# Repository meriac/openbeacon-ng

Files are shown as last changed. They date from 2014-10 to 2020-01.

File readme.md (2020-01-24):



### Introduction

The [OpenBeacon.org](https://www.openbeacon.org/) project provides Active 2.4 GHz RFID Realtime Proximity and Position Tracking using the BlueTooth Low Energy (BLE) compatible [nRF51822](https://www.nordicsemi.com/eng/Products/Bluetooth-Smart-Bluetooth-low-energy/nRF51822) chip from Nordic Semiconductors.

Location tracking using [OpenBeacon tags](https://www.openbeacon.org/device.html) can be implemented by running an [OpenBeacon proximity tag firmware](https://github.com/meriac/openbeacon-ng/tree/master/firmware/nRF51/tag-proximity) that regularly transmits beacon packets. Such packets can then be received by OpenBeacon base stations in the vicinity. Signals received by one or more base stations can then be used to determine the position of each tag in real time.

The proximity feature additionally allows to resolve human contacts by sending detecting other tags in a range of up to 6 meters and a resolution of approximately 0.5 meters. Once a contact is detected, that information is forwarded by the surrounding PoE Ethernet readers to the server infrastructure. Due to the shielding effect of the body, face-to-face contacts can be accurately detected. Optional encryption can make sure, that only base stations inside the system can read the packet information.

On this page you can find the OpenBeacon proximity tag [hardware design](https://github.com/meriac/openbeacon-ng/tree/master/hardware) and the [firmware source code](https://github.com/meriac/openbeacon-ng). You can find more information here:

- See documentation on [Turning the BBC micro:bit into an OpenBeacon Reader](docs/microbit.md) for live sniffing of OpenBeacon sightings.

- [QuickStart for OpenBeacon Tracking](docs/quickstart.md) - this covers serial logging only. For networked live logging, please [contact us](mailto:info@bitmanufactory.com) for more information on our Linux-based network readers (Wifi & Ethernet).

- [Updating your tag firmware](docs/firmware-update.md) - download our latest compiled firmware and update your tags to the latest features.

- [OpenBeacon.org](https://www.openbeacon.org/device.html) Active 2.4GHz RFID Proximity TAG based on the nRF51822 chip from Nordic Semiconductors.

- [SocioPatterns.org](http://www.sociopatterns.org) research project on High-Resolution Social Networks from Wearable Proximity Sensors

- [Contact us](mailto:info@bitmanufactory.com) for further information.

### Acknowledgements

Although the code contributions are acknowledged in the source code headers and history [log files](https://github.com/meriac/openbeacon-ng/commits/master) of the [github repository](https://github.com/meriac/openbeacon-ng), this project lives from invaluable user contributions like rigorous testing, constant suggestion of new features and regular real-life deployments in the field.

The OpenBeacon Team wants to thank [Ciro Cattuto](http://www.cirocattuto.info/) from the [ISI Foundation](http://www.isi.it/) for the great collaboration during the joint development, the ongoing moral support and innovative deployments of our systems.

We especially want to thank Ciro and the [SocioPatterns collaboration](http://www.sociopatterns.org) for providing the scientific background for our platform, the media exposure and the deployments needed for the survival of our project.

### License Information

Please [contact us](mailto:license@bitmanufactory.com) for [obtaining a dual-licensed **closed source license**](mailto:license@bitmanufactory.com?subject=Alternative%20License).

#### Hardware

If you wish, you are free to manufacture the tags yourself. For that purpose you can find the schematics and hardware designs in the directory **hardware**.  The hardware design files in that folder are licensed under the Attribution-ShareAlike 4.0 International ([CC BY-SA 4.0](http://creativecommons.org/licenses/by-sa/4.0/)). We specifically allow commercial usage - as long as you mention the origin of our original design openly.

You can choose to use our services for bulk orders and for custom hardware development based on this and other designs we created in the past. Your financial support allows us to continue working on this awesome project - any help is highly appreciated!

#### Software

The files in the folders **firmware** and **host** are free software. You can redistribute it and/or modify them under the terms of the GNU General Public License as published by the Free Software Foundation (version 2). This program is distributed in the hope that it will be useful, but **without any warranty**; without even the implied warranty of merchantibility or fitness for a particular purpose. See the [GNU General Public License v2](http://www.gnu.org/licenses/gpl-2.0.html) for more details.

### Background Information

#### OpenBeacon.org

The [OpenBeacon.org](https://www.openbeacon.org) project was founded by [Milosch Meriac](https://www.meriac.com) and [Brita Meriac](mailto:brita@bitmanufaktory.com) in 2006 at the Berlin located company Bitmanufaktur GmbH as an open platform for active RFID applications operating in the license free 2.4GHz ISM band. OpenBeacon is based on Open Source software and a very flexible and a open design of a reprogrammable low cost Open Source Active 2.4GHz RFID hardware module. The RFID tag and reader firmware sources are available under GPL license the and tag hardware schematics are available under the open [Creative Commons license](https://creativecommons.org/). We encourage the development of new ideas for OpenBeacon setups and firmware improvements.

#### SocioPatterns

[SocioPatterns](http://www.sociopatterns.org) is an international research collaboration that uses wearable proximity sensors to map human spatial behavior in a variety of environments such as schools, hospitals, offices and social gatherings. During the last 6 years, the SocioPatterns researchers have designed and supervised over 25 data collection campaigns in 10 countries, involving over 50,000 subjects. The resulting high-resolution social networks, [shared with the public](http://www.sociopatterns.org/datasets/) whenever possible, have been used to investigate human mobility, time-varying social networks, infectious disease dynamics, location-based services, and more. The results are reported in 30+ [peer-reviewed scientific publications](http://www.sociopatterns.org/publications/) and have been featured by the [international press](http://www.sociopatterns.org/press/).

The SocioPatterns collaboration was founded by researchers and developers from the following institutions and companies:

- [ISI Foundation](http://www.isi.it/) -- Turin, Italy

- [CNRS - Centre de Physique Theorique](http://www.cpt.univ-mrs.fr) -- Marseille, France

- [ENS Lyon - Laboratoire de Physique](http://www.ens-lyon.fr/PHYSIQUE/) -- Lyon, France

- [Bitmanufactory](https://www.bitmanufactory.com/about/) -- Cambridge, United Kingdom

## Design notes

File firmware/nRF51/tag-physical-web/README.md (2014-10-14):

## OpenBeacon Physical Web Beacon

Our code is hosted on [github.com](https://github.com/meriac/openbeacon-ng). Software development is officially supported for OS X and Linux. Please use the latest [gcc-arm-none-eabi](https://launchpad.net/gcc-arm-embedded) toolchain from launchpad. Thanks a lot to ARM for maintaining [GNU Tools for ARM Embedded Processor](https://launchpad.net/gcc-arm-embedded).

### Hello World!
To demonstrate usage of the included 3D acceleration sensor the included hello world example transmits the URL only while facing forward.

Get the [hardware design](http://get.openbeacon.org/device.html) and [development environment](http://get.openbeacon.org/source/) for creating your own beacons.

You can find the main loop in [firmware/nRF51/tag-physical-web/entry.c](https://github.com/meriac/openbeacon-ng/blob/master/firmware/nRF51/tag-physical-web/entry.c).

### Quick start
For compiling and flashing the firmware source you need to get the [source code](https://github.com/meriac/openbeacon-ng):
```bash
# get the latest source code
git clone https://github.com/meriac/openbeacon-ng
# change into tag directory
cd openbeacon-ng/firmware/nRF51/tag-physical-web
# compile and flash code
make clean flash
```
As you can see the makefile directly supports flashing from command line (under OSX and Linux) by using a [Segger J-Link debug probe](https://www.segger.com/jlink-software.html) from the [Nordic nRF51822 development kit](http://uk.mouser.com/Search/Refine.aspx?Keyword=949-NRF51822-DK).

### Support ###

Please sign up to our [OpenBeacon Group](https://groups.google.com/forum/#!forum/openbeacon) or contact us at [developer@openbeacon.org](mailto:developer@openbeacon.org?subject=Developer%20Support).

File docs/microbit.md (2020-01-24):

# Turning the BBC micro:bit into an OpenBeacon Reader

## Overview

The [BBC micro:bit](https://microbit.org/guide/features/) is a handheld, programmable micro-computer that can be used for all sorts of cool creations, from robots to musical instruments – the possibilities are endless. You can [buy it at most electronis stores](https://microbit.org/resellers/) and at [Amazon](https://www.amazon.com/s?k=micro%3Abit&ref=bl_dp_s_web_0).

In this tutorial we'll show you how to use the micro:bit as an OpenBeacon reader. You can find the [reader-prox-microbit](../firmware/nRF51/reader-prox-microbit) firmware sources in our github repository. We published a precompiled binary firmware image of reader-prox-microbit to turn your micro:bit into an OpenBeacon USB reader. 

## Install Firmware

We provide the [latest precompiled firmware release](../../../releases) in our GitHub repository. Please download the zip file, unpack on your local computer and choose the reader-prox-microbit.bin firmware. Please connect the micro:bit to your computer using a micro USB cable.

Drag & drop the reader-prox-microbit firmware file onto your external device “MICROBIT” within your file manager or finder. The board automatically starts updating the firmware of the main CPU. The process takes less than a second. The red LED square on the board light up five time to indicate a successful boot and resumes fast blinking afterwards in case of picking up traffic by OpenBeacon tags in proximity.

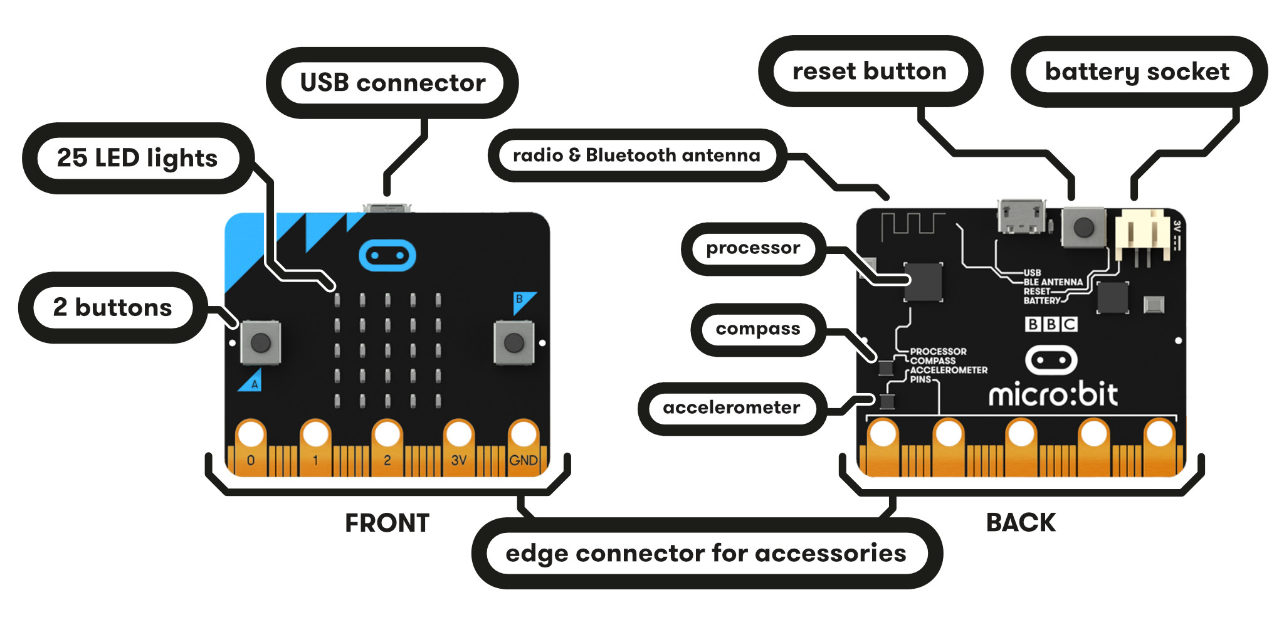
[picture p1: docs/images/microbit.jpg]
Image of micro:bit PCB


## Using the micro:bit OpenBeacon USB Reader

For each blink the received data is sent of over USB serial to the host PC. To see the data you need to connect to the USB serial port created by the micro:bit PCB at 115200 Baud transmission speed (Baudrate). The micro:bit starts in compatibility mode and show the received data in binary mode only:

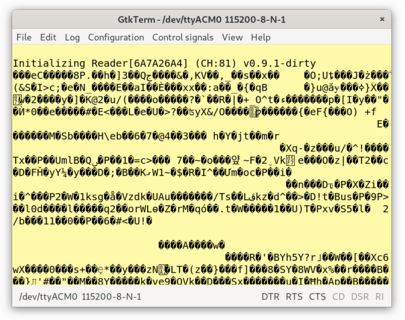
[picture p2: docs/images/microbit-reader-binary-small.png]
Image of micro:bit PCB


By pressing "Button B" briefly, the device can be switched to human readable text mode:

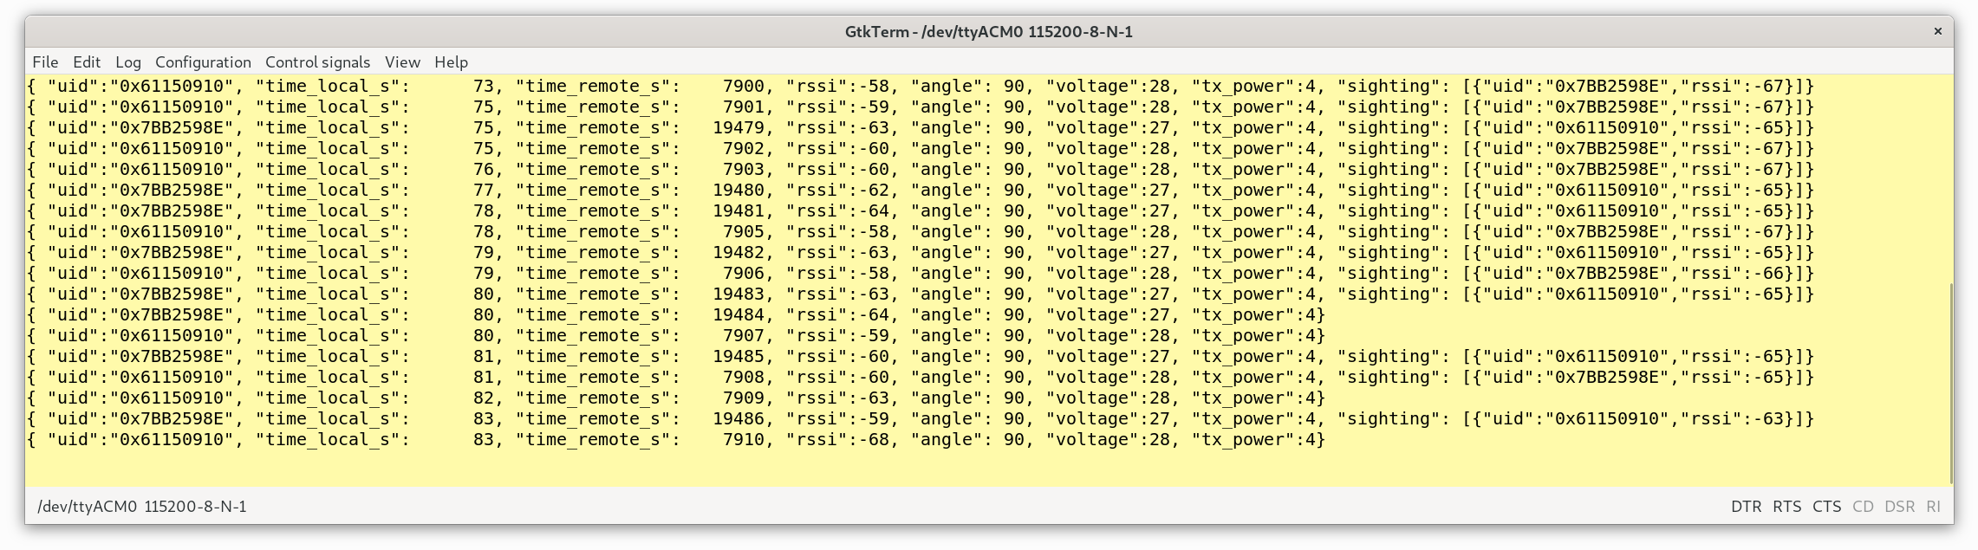
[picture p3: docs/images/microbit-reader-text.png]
Image of micro:bit PCB


By pressing "Button A" briefly, the device can be switched back to binary mode.

For every tag in range of the reader, one line of the data below is printed. You can see below, that the 
tag with ID 0x4A1A13B5 is in very close proximity to three other tags with the IDs 0x7EA7D3ED, 0x3DCFB9B4
and 0x1AFF5471. The reader picks up the reporting tag at -82dBm. Additionally  for each of the tags in
sight of the reporting tag, RSSI-values are reported as well (-63dBm, -66dBm, 58dBm).

The tag also reports its angle, battery voltage and its internal time stamp **time_remote_s**
(seconds after battery insertion). The key here is the **time_local_s** field - which represents the time
in seconds receiving this sighting ince starting the micro:bit.

#### Example Output
```JSON
{
	"uid": "0x4A1A13B5",
	"time_local_s": 1535269163,
	"time_remote_s": 567,
	"rssi": -82,
	"angle": 90,
	"voltage": 28,
	"tx_power": 4,
	"sighting": [{
		"uid": "0x7EA7D3ED",
		"rssi": -63
	}, {
		"uid": "0x3DCFB9B4",
		"rssi": -66
	}, {
		"uid": "0x1AFF5471",
		"rssi": -58
	}]
}
```

## Using openbeacon-sniffer host software with the micro:bit

Below you can find a quick example on how to extract live tag data on an Apple MacBook. In case you see errors trying running the commands ```git``` or ```make``` below, you might have to install them first by running ```xcode-select --install```.

> Please note that the software expects the tag to be in its default mode - the binary mode. The packet decryption and decoding is happening in the host software.

For every tag in range of the reader, one line of the data below is printed. You can see below, that the 
tag with ID 0x4A1A13B5 is in very close proximity to three other tags with the IDs 0x7EA7D3ED, 0x3DCFB9B4
and 0x1AFF5471. The reader picks up the reporting tag at -82dBm. Additionally  for each of the tags in
sight of the reporting tag, RSSI-values are reported as well (-63dBm, -66dBm, 58dBm).

The tag also reports its angle, battery voltage and its internal time stamp **time_remote_s**
(seconds after battery insertion). The key here is the **time_local_s** field - which represents the time
receiving this sighting at the host in seconds.
The time unit for the local time is [Unix Epoch Time](https://www.epochconverter.com/) - which is the number of seconds that have elapsed since January 1, 1970 (midnight UTC/GMT).
By combining the local time and the remote tags time, the log files for each tag can be converted into the common local time.

#### Example Usage
```bash
# Download Sources
git clone https://github.com/meriac/openbeacon-ng
# Change into the openbeacon-sniffer host software directory
cd openbeacon-ng/host/openbeacon-sniffer/

# Compile software
make
# gcc -O3 -W -Wall -Werror -I.  -D_THREAD_SAFE -D_REENTRANT  -c -o openbeacon_sniffer.o openbeacon_sniffer.c
# gcc -O3 -W -Wall -Werror -I.  -D_THREAD_SAFE -D_REENTRANT  -c -o crypto.o crypto.c
# gcc -O3 -W -Wall -Werror -I.  -D_THREAD_SAFE -D_REENTRANT openbeacon_sniffer.o crypto.o -o openbeacon_sniffer

# Run software - note that the '*' is automatically expanded to the device name of your
# OpenBeacon programmer. Each had a different name - mine is for example /dev/tty.usbserial-AK0535TL
# The last (and optional) parameter is the optional baud rate setting - in our case 115200 Baud.
./openbeacon_sniffer /dev/tty.usbserial-* 115200
#  opening /dev/ttyACM0 @ 115200 Baud
#  { "uid":"0x4A1A13B5", "time_local_s":1535276483, "time_remote_s":     382, "rssi":-84, "angle": 90, "voltage":2.7, "tx_power":4}
#  { "uid":"0x1AFF5471", "time_local_s":1535276484, "time_remote_s":    7894, "rssi":-71, "angle": 90, "voltage":2.8, "tx_power":4}
#  { "uid":"0x7EA7D3ED", "time_local_s":1535276484, "time_remote_s":    7897, "rssi":-78, "angle": 90, "voltage":2.8, "tx_power":4, "sighting": [{"uid":"0x4A1A13B5","rssi":-66},{"uid":"0x1AFF5471","rssi":-57}]}
#  { "uid":"0x4A1A13B5", "time_local_s":1535276484, "time_remote_s":     383, "rssi":-83, "angle": 90, "voltage":2.8, "tx_power":4}
#  { "uid":"0x7EA7D3ED", "time_local_s":1535276484, "time_remote_s":    7898, "rssi":-82, "angle": 90, "voltage":2.8, "tx_power":4}
#  { "uid":"0x1AFF5471", "time_local_s":1535276485, "time_remote_s":    7895, "rssi":-74, "angle": 90, "voltage":2.8, "tx_power":4, "sighting": [{"uid":"0x4A1
```
For writing the collected tag data into a file, you simply redirect into a log file:
```bash
./openbeacon_sniffer /dev/tty.usbserial-* 115200 >>logfile.json
```
Please note that '>>' keeps on appending to **logfile.json** when you run openbeacon_sniffer multiple
times. This way you can combine data from multiple runs in case you have to replaunch openbeacon_sniffer.

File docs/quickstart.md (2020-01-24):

# QuickStart for OpenBeacon Tracking

## Turning the BBC micro:bit into an OpenBeacon Reader

See documentation on [Turning the BBC micro:bit into an OpenBeacon Reader](microbit.md) for live sniffing of OpenBeacon sightings. For using the [OpenBeacon Programmer](https://www.openbeacon.org/device.html) instead for offline data data dumping and for live OpenBeacon monotoring, see the documentation below.

## Offline Logging

When using the [Proximity Tag](../firmware/nRF51/tag-proximity) firmware,
tags can store many days of tag sightings in their proximity inside their 8MB external flash storage by using data compression.

For retrieving the stored data, we made the [tag-dumper](../host/tag-dumper) host software available. An [OpenBeacon Programmer](https://www.openbeacon.org/device.html) is used to connecting tag to a host computer for data extraction. **Always remove batteries from tags before placing them into OpenBeacon Programmer. You might destroy the reader or the tag otherwise.**

For each observation of different tags, the proximity tag stores the local time when observing the
opposite tag, the power level of the received data packet in dBm, the current angle of the tag and the
remote tag id **tag_them**. For convenience in the data processing, [tag-dumper](../host/tag-dumper) also
displays the tag ID of the currently connected tag.

> In case the tag is power-cycled, the tag time starts counting from zero again. To protect
> previous data, it is not erased unless explicitely wanted. To show the user that the tag is now counting
> at a different time offset, the rumber in **group** is incremented.
>
> For simplicity we therefore encourage to erase the tag before deployment using the programmer -
> and not to insert batteries before tags are handed out to users. These tags should therefore only
> ever display a group number of '1' and multiple time offsets can be therefore ignored.

### Retreving Offline Data

Below you can find a quick example on how to extract tag data on an Apple MacBook.
First you need to connect the [OpenBeacon Programmer](https://www.openbeacon.org/device.html) to your
laptop by using a MicroUSB cable. The nRF51-DK development kit does not need to be connected for extracting data - the development kit is only required for updating tag firmware.

> Please [update the  firmware](firmware-update.md) of your tag to **tag-proximity-log-tag.bin**
> for using the offline logging mode.

In case you see errors trying running the commands ```git``` or ```make``` below,
you might have to install them first by running ```xcode-select --install```.
```bash
# Download Sources
git clone https://github.com/meriac/openbeacon-ng
# Change into the tag-dumper host software directory
cd openbeacon-ng/host/tag-dumper/
# Compile software
make
# Run software - note that the '*' is automatically expanded to the device name of your
# OpenBeacon programmer. Each had a different name - mine is for example /dev/tty.usbserial-AK0535TL
./tag-dumper /dev/tty.usbserial-*
#  Received Tag ID=0x4A1A13B5
#  Received Tag ID=0x4A1A13B5
#  Received Tag ID=0x4A1A13B5
#  Received Tag ID=0x4A1A13B5
```
After running tag-dumper, it will print once per second *Received Tag ID=0x.....*.

If you now press the button on the tag for one second, it will start dumping stored data. Here's an
single example dataset similar to the ones you will see:
```JSON
{
	"tag_me": "0x4A1A13B5",
	"tag_them": "0x1AFF5471",
	"time_local_s": 3027,
	"time_remote_s": 3033,
	"rssi": -58,
	"angle": 90,
	"group": 1
}
```
For writing the collected tag data into a file, you simply redirect into a log file:
```bash
./tag-dumper /dev/tty.usbserial-* >>logfile.json
#  Received Tag ID=0x4A1A13B5
#  Found new log group[0] at page 0
#  Received Tag ID=0x4A1A13B5
```
Please note that '>>' keeps on appending to **logfile.json** when you run tag-dumper multiple times.
This way you can combine data from multiple runs in case you have to replaunch the tag-dumper.

### Erasing the tag

After dumping the data, you might want to erase the tag again to prime it for collecting new data.
For erasing the tag, you need to press the button on the tag for more than 3 seconds till the LED
starts blinking very quickly. Erasing the tag takes 10's of seconds. Once the erasing stopped,
the tag will go back into idle mode.

## Live Wireless Sniffing of OpenBeacon Tags

> See latest documentation on [Turning the BBC micro:bit into an OpenBeacon Reader](microbit.md) for live sniffing of OpenBeacon sightings.

The same hardware as used can be used to observe tags in operation. By using the [reader-prox](../firmware/nRF51/reader-prox) firmware and the [openbeacon-sniffer](../host/openbeacon-sniffer) software, a tag sitting
in the [OpenBeacon Programmer](https://www.openbeacon.org/device.html) sniffs and decodes tag
transmissions off the air.

For every tag in range of the reader, one line of the data below is printed. You can see below, that the 
tag with ID 0x4A1A13B5 is in very close proximity to three other tags with the IDs 0x7EA7D3ED, 0x3DCFB9B4
and 0x1AFF5471. The reader picks up the reporting tag at -82dBm. Additionally  for each of the tags in
sight of the reporting tag, RSSI-values are reported as well (-63dBm, -66dBm, 58dBm).

The tag also reports its angle, battery voltage and its internal time stamp **time_remote_s**
(seconds after battery insertion). The key here is the **time_local_s** field - which represents the time
receiving this sighting at the host running [openbeacon-sniffer](../host/openbeacon-sniffer).
The time unit for the local time is [Unix Epoch Time](https://www.epochconverter.com/) - which is the number of seconds that have elapsed since January 1, 1970 (midnight UTC/GMT).
By combining the local time and the remote tags time, the log files for each tag can be converted into the common local time.

```JSON
{
	"uid": "0x4A1A13B5",
	"time_local_s": 1535269163,
	"time_remote_s": 567,
	"rssi": -82,
	"angle": 90,
	"voltage": 2.8,
	"tx_power": 4,
	"sighting": [{
		"uid": "0x7EA7D3ED",
		"rssi": -63
	}, {
		"uid": "0x3DCFB9B4",
		"rssi": -66
	}, {
		"uid": "0x1AFF5471",
		"rssi": -58
	}]
}
```

### Retreving Live Data
Below you can find a quick example on how to extract tag data on an Apple MacBook.
First you need to connect the [OpenBeacon Programmer](https://www.openbeacon.org/device.html) to your
laptop by using a MicroUSB cable. The nRF51-DK development kit does not need to be connected for extracting data - the development kit is only required for updating tag firmware.

> Please [update the firmware](firmware-update.md) of your tag to **reader-prox.bin**
> for running live wireless sniffing.

In case you see errors trying running the commands ```git``` or ```make``` below,
you might have to install them first by running ```xcode-select --install```.
```bash
# Download Sources
git clone https://github.com/meriac/openbeacon-ng
# Change into the openbeacon-sniffer host software directory
cd openbeacon-ng/host/openbeacon-sniffer/

# Compile software
make
#  gcc -O3 -W -Wall -Werror -I. -D_THREAD_SAFE -D_REENTRANT  -c -o openbeacon_sniffer.o openbeacon_sniffer.c
#  gcc -O3 -W -Wall -Werror -I. -D_THREAD_SAFE -D_REENTRANT  -c -o crypto.o crypto.c
#  gcc -O3 -W -Wall -Werror -I. -D_THREAD_SAFE -D_REENTRANT  -c -o crc32.o crc32.c
#  gcc -O3 -W -Wall -Werror -I. -D_THREAD_SAFE -D_REENTRANT openbeacon_sniffer.o crypto.o crc32.o -o openbeacon_sniffer

# Run software - note that the '*' is automatically expanded to the device name of your
# OpenBeacon programmer. Each had a different name - mine is for example /dev/tty.usbserial-AK0535TL
./openbeacon_sniffer /dev/tty.usbserial-*
#  fd=3
#  { "uid":"0x4A1A13B5", "time_local_s":1535276483, "time_remote_s":     382, "rssi":-84, "angle": 90, "voltage":2.7, "tx_power":4}
#  { "uid":"0x1AFF5471", "time_local_s":1535276484, "time_remote_s":    7894, "rssi":-71, "angle": 90, "voltage":2.8, "tx_power":4}
#  { "uid":"0x7EA7D3ED", "time_local_s":1535276484, "time_remote_s":    7897, "rssi":-78, "angle": 90, "voltage":2.8, "tx_power":4, "sighting": [{"uid":"0x4A1A13B5","rssi":-66},{"uid":"0x1AFF5471","rssi":-57}]}
#  { "uid":"0x4A1A13B5", "time_local_s":1535276484, "time_remote_s":     383, "rssi":-83, "angle": 90, "voltage":2.8, "tx_power":4}
#  { "uid":"0x7EA7D3ED", "time_local_s":1535276484, "time_remote_s":    7898, "rssi":-82, "angle": 90, "voltage":2.8, "tx_power":4}
#  { "uid":"0x1AFF5471", "time_local_s":1535276485, "time_remote_s":    7895, "rssi":-74, "angle": 90, "voltage":2.8, "tx_power":4, "sighting": [{"uid":"0x4A1
```
For writing the collected tag data into a file, you simply redirect into a log file:
```bash
./openbeacon_sniffer /dev/tty.usbserial-* >>logfile.json
```
Please note that '>>' keeps on appending to **logfile.json** when you run openbeacon_sniffer multiple
times. This way you can combine data from multiple runs in case you have to replaunch openbeacon_sniffer.

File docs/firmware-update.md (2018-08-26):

# Updating the OpenBeacon Tag

## Connecting Nordic nRF51-DK development kit and OpenBeacon Programmer

The [OpenBeacon Programmer](https://www.openbeacon.org/device.html) connects with a flat ribbon cable to the nRF51-development board. Please make sure, that the red marking on the flat cable is pointing towards the USB connector of the OpenBeacon Programmer. Use the pins labeled “Debug Out” next to the USB connector to connect the flat ribbon cable to the the nRF51-development board. Both boards, OpenBeacon Programmer and nRF51, use a Micro-USB cable each with your local laptop or computer. Slide the switch next to the USB connector on the nRF51-development board to position “ON”.

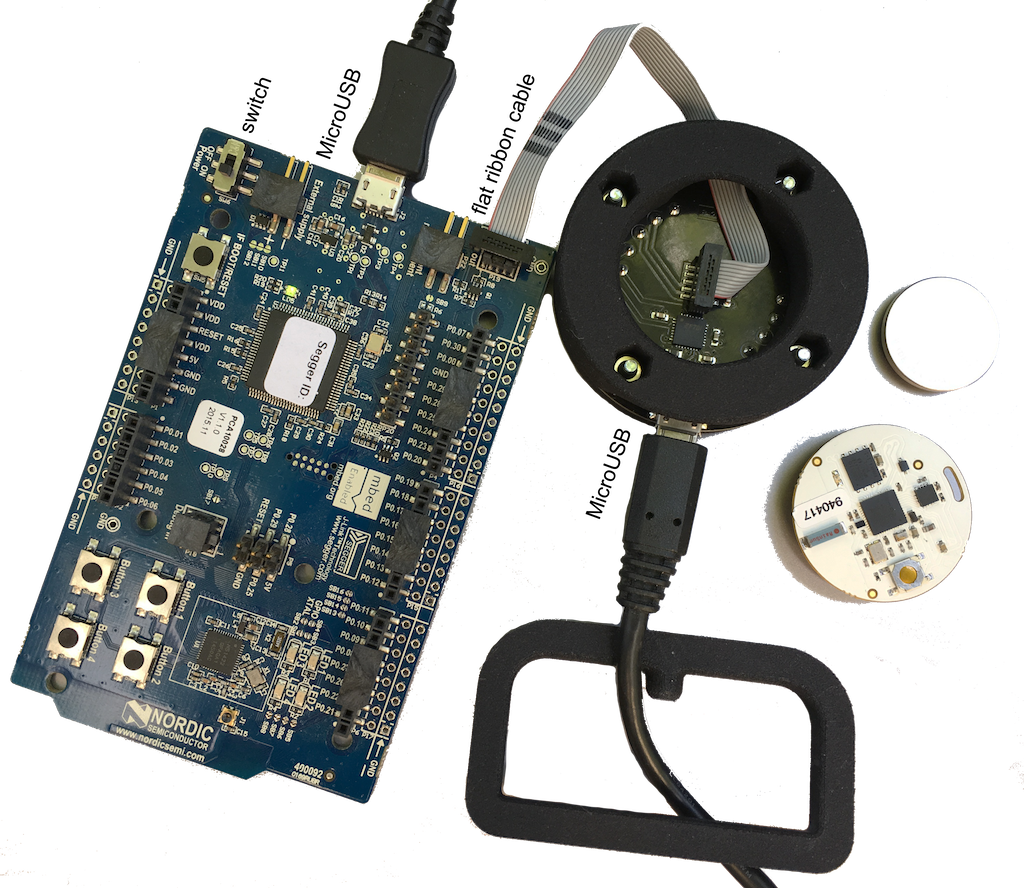
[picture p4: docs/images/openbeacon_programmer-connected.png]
Image of OpenBeacon Programmer connected to nRF52-board


You may check both USB connections by running ```lsusb``` on Linux or the command ```system_profiler SPUSBDataType``` in your OS X terminal. It should give you the manufacturer information “FTDI” for the OpenBeacon Programmer and “Segger” for the nRF51-development board.

The connection should pop up as an external USB device labeled “JLINK” in your local file manager or finder.

Remove the battery from the tag you want to flash and place it on the golden flexible pins within the round black frame of the OpenBeacon Programmer. The battery connector should face downwards and the little slit in the tag should align with the corresponding embossment in the round frame. Place the black bracket over tag and programmer to hold both in place or press and hold gently with your hand while flashing the firmware.

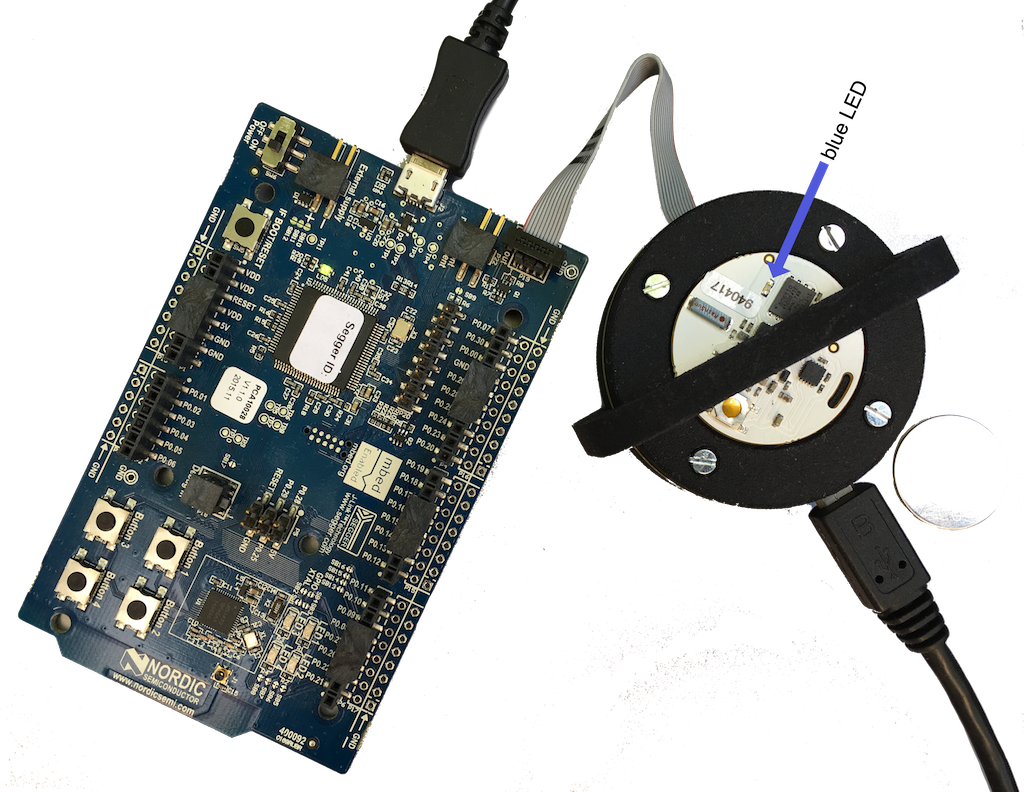
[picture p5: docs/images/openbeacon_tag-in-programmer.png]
Image of OpenBeacon Tag inserted in Programmer


## Choosing latest firmware

We provide the [latest firmware release](../../../releases) in our GitHub. Please download the zip file, unpack on your local computer and choose the relevant firmware. You will need at least two different types of firmware: One for marking locations ("marker tag”) and the other for the tags on moving persons/objects ("log tag"). Other firmware for special applications from previous studies are also available.

Select, copy and paste drop the chosen firmware file into your external device “JLINK” within your file manager or finder. The board automatically starts updating the firmware of the tag. The process takes less than a second. The blue LED on the tag lights up for 2 seconds to indicate the successful process and resumes fast blinking afterwards. You may now remove the tag.

When you insert the battery into the tag, the blue LED will light up for 2 seconds and will than continue to blink every 5 seconds. Please make sure to insert the CR2032 batteries just before you hand out the tags to ensure long battery lifetime and only relevant data is stored.

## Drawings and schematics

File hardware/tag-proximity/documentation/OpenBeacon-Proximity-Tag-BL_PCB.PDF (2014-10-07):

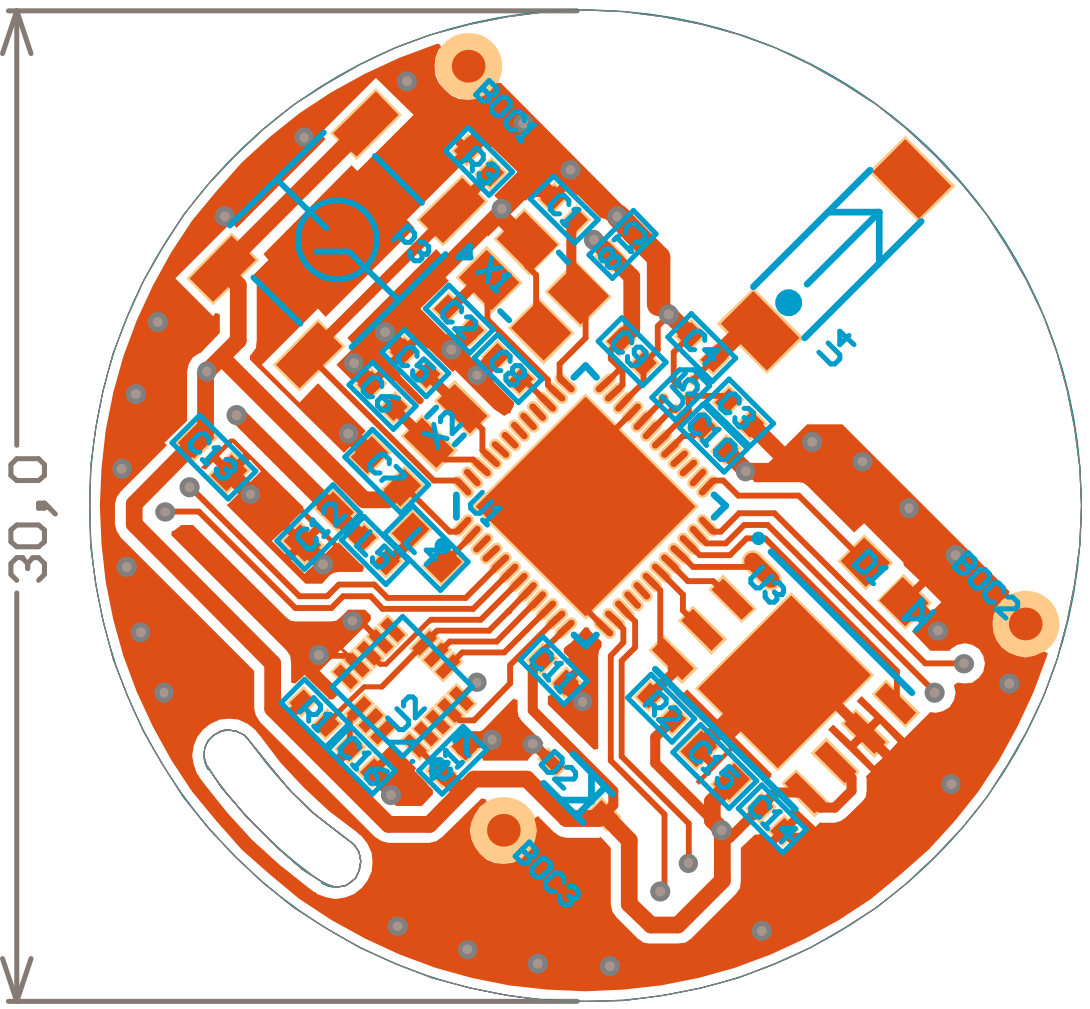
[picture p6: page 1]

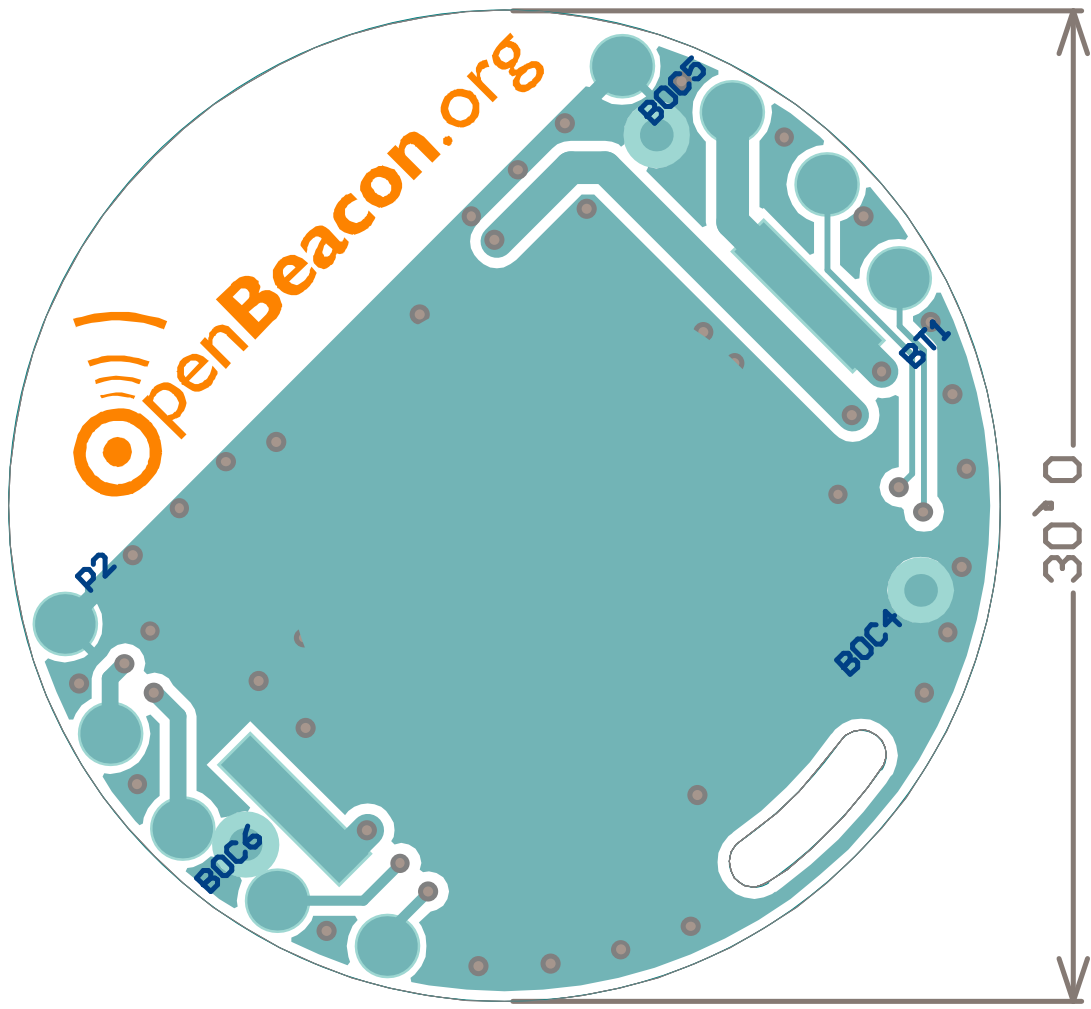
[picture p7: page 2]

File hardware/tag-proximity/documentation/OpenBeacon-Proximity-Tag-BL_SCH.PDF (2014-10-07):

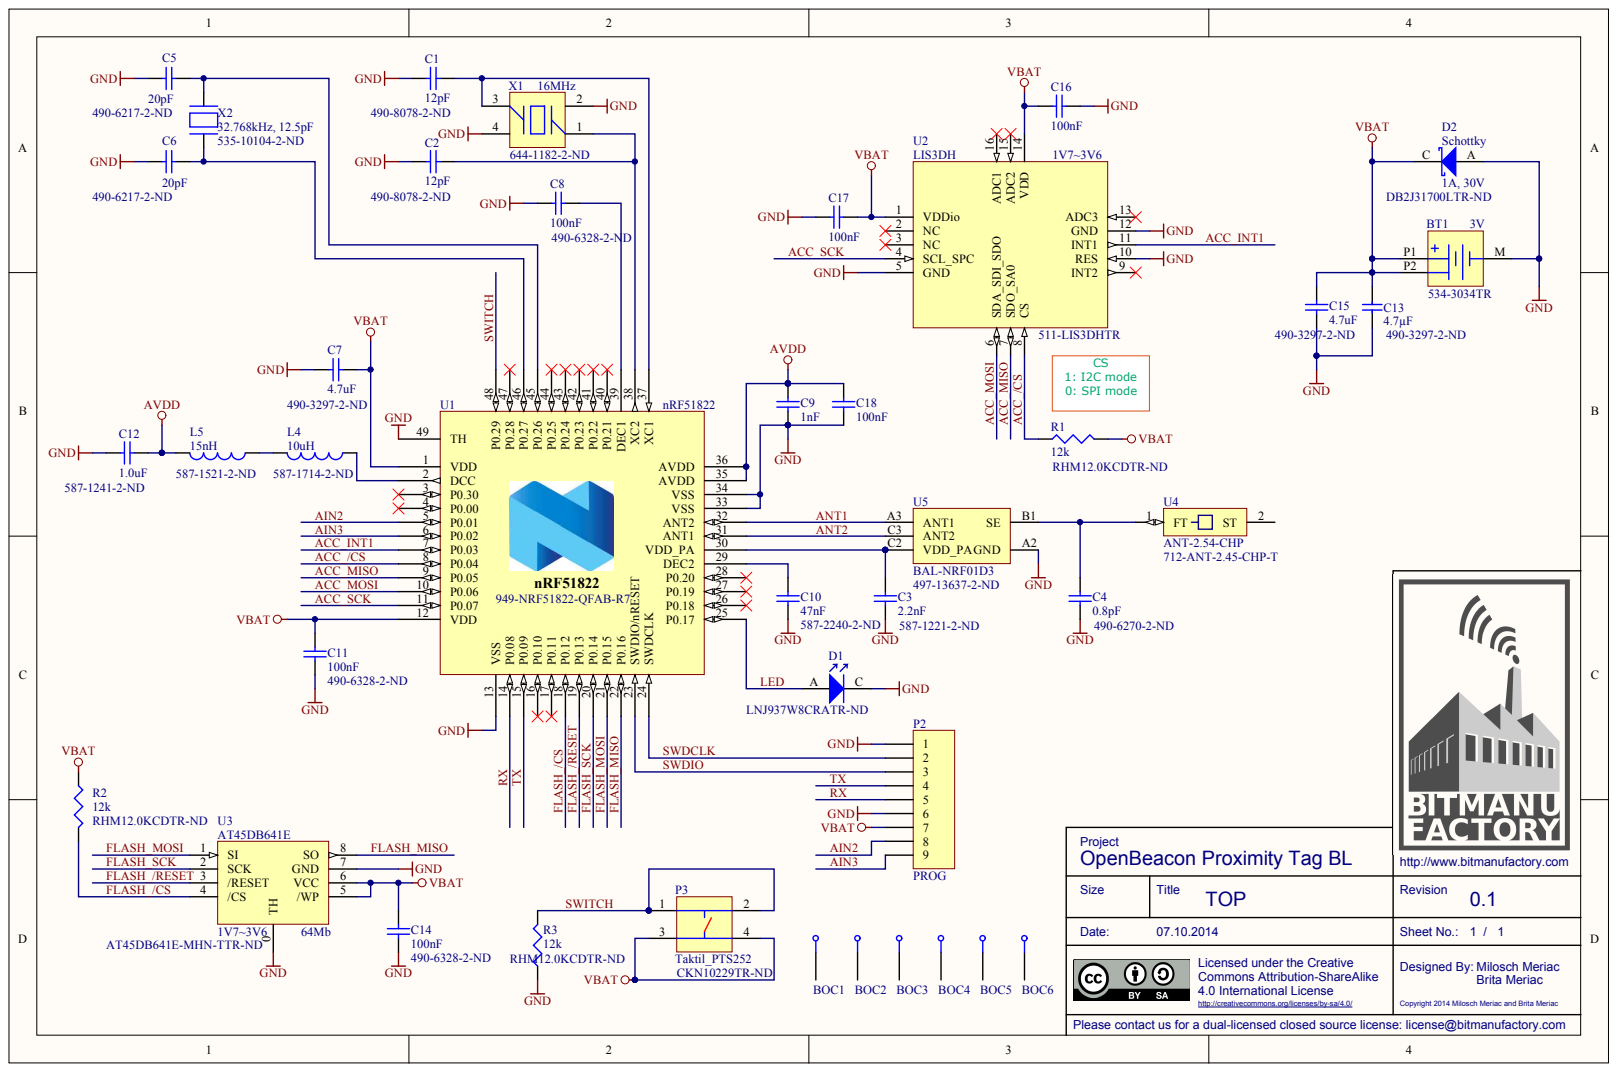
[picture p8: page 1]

Project
OpenBeacon Proximity Tag BL

http://www.bitmanufactory.com

Licensed under the Creative
Commons Attribution-ShareAlike
4.0 International License

http://creativecommons.org/licenses/by-sa/4.0/

Copyright 2014 Milosch Meriac and Brita Meriac

Please contact us for a dual-licensed closed source license: license@bitmanufactory.com

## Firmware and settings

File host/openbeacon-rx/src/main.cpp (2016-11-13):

/***************************************************************
 *
 * OpenBeacon.org - OnAir protocol position tracker
 *
 * uses a physical model and statistical analysis to calculate
 * positions of tags
 *
 * Copyright 2009-2015 Milosch Meriac <milosch@meriac.com>
 *
 ***************************************************************/

/*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
 You should have received a copy of the GNU Affero General Public License
 along with this program; if not, write to the Free Software Foundation,
 Inc., 51 Franklin Street, Fifth Floor, Boston, MA 02110-1301 USA.
*/

#include <stdio.h>
#include <stdlib.h>
#include <string.h>
#include <stdint.h>
#include <unistd.h>
#include <stdarg.h>
#include <sys/time.h>
#include <arpa/inet.h>
#include <netinet/ip.h>
#include <netinet/in.h>
#include <netinet/udp.h>
#include <sys/types.h>
#include <sys/socket.h>
#include <pthread.h>
#include <math.h>

#include "main.h"
#include "helper.h"
#include "crypto.h"
#include "replay.h"
#include "network.h"
#include "bmMapHandleToItem.h"
#include "../BeaconPositions.h"

#define TAG_DAMPEN 10.0

#define TAGBUTTON_TIME 10
#define TAGAGGREGATION_TIME 30
#define PROXAGGREGATION_TIME 10
#define MAX_PROXIMITY_SLOTS 32

#define PROX_STEP (1/PROXAGGREGATION_TIME)
#define PROX_WEIGHT(x) (1-(PROX_STEP*x))

#if __APPLE__ && __MACH__
#define exp10(x) __exp10(x)
#endif

typedef struct
{
	uint32_t tag_id, epoch;
	float voltage;
	int angle;
	bool calibrated, fixed, visible;
	double last_seen;
	uint32_t button_time;
	uint32_t last_reader_id;
	int Fcount;
	double Fx, Fy;
	double rx_loss, tx_loss, px_power;
	double pX, pY, vX, vY;
} TTagItem;

typedef struct
{
	uint32_t last_seen;
	int power;
	uint32_t distance;
} TTagProximitySlot;

typedef struct
{
	uint32_t tag1, tag2;
	TTagItem *tag1p, *tag2p;
	uint32_t last_seen;
	int last_power;
	bool calibrated;
	double tag1_calrx,tag2_calrx;
	uint32_t fifo_pos;
	TTagProximitySlot fifo[MAX_PROXIMITY_SLOTS];
} TTagProximity;

static FILE* g_out;
static bool g_first;
static bmMapHandleToItem g_map_reader, g_map_tag, g_map_proximity;

static uint32_t g_total_crc_ok, g_total_crc_errors;
static uint32_t g_ignored_protocol, g_invalid_protocol, g_unknown_reader;
static uint32_t g_doubled_reader;
static uint8_t g_decrypted_one;

#define STRENGTH_LEVELS_COUNT 4

static void
process_packet(double timestamp, uint32_t reader_id, const TBeaconNgTracker &track)
{
	int i;
	double cal;
	uint32_t tag1, tag2;
	TTagItem *tag, *tag1p, *tag2p;
	TTagProximity *prox;
	TTagProximitySlot *prox_slot;
	const TBeaconNgSighting *slot;
	const TBeaconItem *beacon;
	pthread_mutex_t *tag_mutex, *prox_mutex;

	/* find tag */
	if((tag = (TTagItem*)g_map_tag.Add(track.uid, &tag_mutex))==NULL)
		diep("can't add tag item");

	/* tag seen first time */
	if(!tag->tag_id)
	{
		tag->tag_id = track.uid;
		tag->calibrated = false;
		tag->epoch = 0;

		/* check for fixed beacons ID's */
		for(i=0; i<BEACON_COUNT; i++)
		{
			beacon = &g_BeaconList[i];
			if(tag->tag_id == beacon->id)
			{
				tag->fixed = tag->visible = true;
				tag->pX = beacon->pX;
				tag->pY = beacon->pY;
			}
		}
	}

#ifdef REPLAY_PROTECTION
	/* ignore doubled/replayed packets */
	if(track.epoch <= tag->epoch)
	{
		pthread_mutex_unlock (tag_mutex);
		return;
	}
#endif

	/* remember reader time */
	tag->epoch = track.epoch;
	tag->last_seen = timestamp;
	tag->last_reader_id = reader_id;
	tag->voltage = track.voltage/10.0;
	tag->angle = track.angle;
	if(track.proto & RFBPROTO_PROTO_BUTTON)
		tag->button_time = timestamp;

	switch(track.proto & RFBPROTO_PROTO_MASK)
	{
		case RFBPROTO_BEACON_NG_SIGHTING:
		{
			slot = track.p.sighting;
			for(i=0; i<CONFIG_SIGHTING_SLOTS; i++)
			{
				/* ignore empty slots */
				if(!slot->uid)
					continue;

				/* sort UIDs */
				if(track.uid<slot->uid)
				{
					tag1p = tag;
					tag2p = NULL;
					tag1 = track.uid;
					tag2 = slot->uid;
				}
				else
				{
					tag1p = NULL;
					tag2p = tag;
					tag1 = slot->uid;
					tag2 = track.uid;
				}

				/* look up connection */
				if ((prox = (TTagProximity *)
					g_map_proximity.Add ((((uint64_t) tag1) << 32) | tag2,
					&prox_mutex)) == NULL)
					diep ("can't add tag proximity sighting");
				/* first occurence */
				if(!prox->tag1)
				{
					prox->tag1 = tag1;
					prox->tag1p = tag1p;
					prox->tag2 = tag2;
					prox->tag2p = tag2p;
				}

				/* erase old sigthings */
				if((timestamp-prox->last_seen)>=PROXAGGREGATION_TIME)
				{
					prox->fifo_pos = 0;
					bzero(&prox->fifo, sizeof(prox->fifo));
				}
				/* remember time */
				prox->last_seen = timestamp;
				prox->last_power = slot->rx_power;

				/* remember sighting */
				prox_slot = &prox->fifo[prox->fifo_pos++];
				if(prox->fifo_pos>=MAX_PROXIMITY_SLOTS)
					prox->fifo_pos = 0;
				prox_slot->last_seen =  timestamp;
				prox_slot->power = slot->rx_power;

				/* populate second tag pointer */
				if(!prox->tag1p)
					prox->tag1p = (TTagItem*)g_map_tag.Find(prox->tag1, NULL);
				if(!prox->tag2p)
					prox->tag2p = (TTagItem*)g_map_tag.Find(prox->tag2, NULL);

				/* pre-calculate calibration values */
				if(prox->calibrated)
				{
					cal = (tag->tag_id == tag1) ? prox->tag1_calrx : prox->tag2_calrx;
					/* calculate distance in mm */
					prox_slot->distance =
						(exp10((cal - prox_slot->power)/20.0)/
						(41.88*(2400+CONFIG_PROX_CHANNEL)))*1000000;
				}
				else
				{
					prox_slot->distance = 0;

					/* wait till both sides are calibrated */
					if(	prox->tag1p && prox->tag2p &&
						prox->tag1p->calibrated &&
						prox->tag2p->calibrated)
					{
						prox->calibrated = true;
						prox->tag1_calrx =
							prox->tag1p->rx_loss +
							prox->tag2p->px_power +
							prox->tag2p->tx_loss;
						prox->tag2_calrx =
							prox->tag2p->rx_loss +
							prox->tag1p->px_power +
							prox->tag1p->tx_loss;
					}
				}

				/* release proximity object */
				pthread_mutex_unlock (prox_mutex);
				/* next slot */
				slot++;
			}
			break;
		}

		case RFBPROTO_BEACON_NG_STATUS:
		{
			tag->calibrated = true;
			tag->rx_loss  = track.p.status.rx_loss/100.0;
			tag->tx_loss  = track.p.status.tx_loss/100.0;
			tag->px_power = track.p.status.px_power/100.0;
			break;
		}
	}

	/* release tag object */
	pthread_mutex_unlock (tag_mutex);
}

void
print_packet(FILE *out, uint32_t reader_id, const TBeaconNgTracker &track)
{
	uint32_t t;
	const TBeaconNgSighting *slot;

	/* show common fields */
	fprintf(out, "{\"id\":\"0x%08X\",\"t\":%i,\"voltage\":%1.1f,\"angle\":%03i,",
		track.uid,
		track.epoch,
		track.voltage/10.0,
		track.angle
	);

	/* show specific fields */
	switch(track.proto & RFBPROTO_PROTO_MASK)
	{
		case RFBPROTO_BEACON_NG_SIGHTING:
		{
			fprintf(out, "\"sighting\"=[");
			slot = track.p.sighting;
			for(t=0; t<CONFIG_SIGHTING_SLOTS; t++)
			{
				if(slot->uid)
				{
					fprintf(out, "%s{\"id\":\"0x%08X\",\"dBm\":%03i}",
						t ? ",":"",
						slot->uid,
						slot->rx_power
					);
				}
				slot++;
			}
			fprintf(out, "]");
			break;
		}

		case RFBPROTO_BEACON_NG_STATUS:
		{
			fprintf(out, "\"status\":{\"rx_loss\":%1.2f,\"tx_loss\":%1.2f,\"px_power\":%2.0f,\"ticks\":%06i}",
				track.p.status.rx_loss/100.0,
				track.p.status.tx_loss/100.0,
				track.p.status.px_power/100.0,
				track.p.status.ticks
			);
			break;
		}
	}

	fprintf(out, "}\n\r");
}

int
parse_packet (double timestamp, uint32_t reader_id, const void *data, int len)
{
	uint32_t t;
	const TBeaconLogSighting *pkt;
	TBeaconNgTracker track;

	if(len<(int)sizeof(TBeaconLogSighting))
		return len;

	pkt = (const TBeaconLogSighting*)data;
	if(pkt->hdr.protocol != BEACONLOG_SIGHTING)
	{
		fprintf(stderr, " Invalid protocol [0x%02X]\n\r", pkt->hdr.protocol);
		return len;
	}

	t = ntohs(pkt->hdr.size);
	if(ntohs(t != sizeof(TBeaconLogSighting)))
	{
		fprintf(stderr, " Invalid packet size (%i expected, %u received)\n\r", (int)sizeof(TBeaconLogSighting), t);
		return len;
	}
	
	if(ntohs(pkt->hdr.icrc16) != icrc16(&pkt->hdr.protocol, (sizeof(TBeaconLogSighting)-sizeof(pkt->hdr.icrc16))))
	{
		fprintf(stderr, " Invalid packet CRC\n\r");
		return len;
	}

	/* decrypt valid packet */
	if((t = aes_decr(&pkt->log, &track, sizeof(track), CONFIG_SIGNATURE_SIZE))!=0)
	{
		fprintf(stderr, " Failed decrypting packet with error [%i]\n\r", t);
		return len;
	}

	switch(track.proto & RFBPROTO_PROTO_MASK)
	{
		case RFBPROTO_BEACON_NG_SIGHTING:
		case RFBPROTO_BEACON_NG_STATUS:
			/* show & process latest packet */
//			print_packet(stdout, reader_id, track);
			process_packet(timestamp, reader_id, track);
			return sizeof(TBeaconLogSighting);

		default:
			fprintf(stderr, " Unknown protocol [0x%02X]\n\r", track.proto);
			return len;
	}
}

static void
thread_iterate_tag (void *Context, double timestamp, bool realtime)
{
	int delta;
	double dx, dy, distance;
	TTagItem *tag = (TTagItem*)Context;

	/* ignore empty slots */
	if(!tag->last_seen)
		return;

	/* calculate delta time since last sighting - expired ? */
	delta = timestamp - tag->last_seen;
	if (delta >= TAGAGGREGATION_TIME)
		return;

	if(g_first)
	{
		fprintf(g_out,"\n  ],\n  \"tag\":[");
	}
	fprintf(g_out,"%s\n    {\"id\":%u,\"hex\":\"0x%08X\",\"age\":%i,\"angle\":%i,\"voltage\":%1.1f",
		g_first ? "":",",
		tag->tag_id,
		tag->tag_id,
		delta,
		tag->angle,
		tag->voltage
	);
	g_first = false;

	if((timestamp - tag->button_time)<=TAGBUTTON_TIME)
		fprintf(g_out,",\"button\":true");

	if(tag->fixed)
		fprintf(g_out,",\"fixed\":true");

	if(tag->visible)
		fprintf(g_out,",\"px\":%i,\"py\":%i", (int)tag->pX, (int)tag->pY);

	if(tag->Fcount)
	{
		dx = tag->Fx/tag->Fcount;
		dy = tag->Fy/tag->Fcount;
		distance = sqrt(dx*dx + dy*dy);
		if(distance>=0.1)
		{
			/* move only in unity-steps */
			tag->pX += dx/distance;
			tag->pY += dy/distance;
		}
//		fprintf(g_out,",\"Fx\":%1.1f,\"Fy\":%1.1f", dx, dy);
	}
	tag->visible = tag->fixed || (tag->Fcount>0);

	fprintf(g_out,"}");
}

static void
thread_reset_tag (void *Context, double timestamp, bool realtime)
{
	TTagItem *tag = (TTagItem*)Context;

	tag->Fx = tag->Fy = 0;
	tag->Fcount = 0;
}

static void thread_update_tag_speed(TTagItem *tag, const TTagItem *beacon, double power)
{
	double dX, dY, dist;

	/* calculate force unity vector */
	dX = beacon->pX - tag->pX;
	dY = beacon->pY - tag->pY;
	dist = sqrt(dX*dX + dY*dY);

	if(dist>0.1)
	{
		dX /= dist;
		dY /= dist;
	}

	/* simple power multilateration - FIXME! */
	power = fabs(power);
	if(power <= 40)
		power = 1;
	else
	{
		power -= 39;
		if(power > 40)
			power = 40;
		power = 40 - power;
	}

	/* register power */
	tag->Fx += dX * power;
	tag->Fy += dY * power;
	tag->Fcount++;
}

static void
thread_iterate_prox (void *Context, double timestamp, bool realtime)
{
	double weigth, totalp, totald, power;
	int i, j, count, delta;
	uint32_t dist;
	TTagProximitySlot *slot;
	TTagProximity *prox = (TTagProximity*)Context;

	/* ignore empty slots */
	if(!prox->last_seen)
		return;

	/* calculate delta time since last sighting - expired ? */
	delta = timestamp - prox->last_seen;
	if (delta >= PROXAGGREGATION_TIME)
	{
		prox->last_seen = prox->fifo_pos = 0;
		bzero(&prox->fifo, sizeof(prox->fifo));
		return;
	}

	dist = 0;
	count = 0;
	slot = prox->fifo;
	totalp = totald = power = 0;
	for(i=0; i<MAX_PROXIMITY_SLOTS; i++, slot++)
	{
		j = timestamp - slot->last_seen;
		if(slot->last_seen && (j <= PROXAGGREGATION_TIME))
		{
			count++;

			weigth = PROX_WEIGHT(j);
			totalp += weigth;
			power += slot->power * weigth;

			if(slot->distance)
			{
				totald += weigth;
				dist+=slot->distance;
			}
		}
	}

	/* ignore empty sets */
	if(!count)
		return;

	/* normalize data */
	power/=totalp;

	/* update delta-Velocity */
	if(prox->tag1p && prox->tag2p)
	{
		if(prox->tag1p->fixed && !prox->tag2p->fixed)
			thread_update_tag_speed(prox->tag2p, prox->tag1p, power);
		else
			if(!prox->tag1p->fixed && prox->tag2p->fixed)
				thread_update_tag_speed(prox->tag1p, prox->tag2p, power);
	}

	fprintf(g_out,"%s\n    {\"tag\":[%u,%u],\"age\":%i,\"count\":%u,\"power\":%1.1f",
		g_first ? "":",",
		prox->tag1,
		prox->tag2,
		delta,
		count,
		power
	);
	g_first = false;

	if(totald>0)
		fprintf(g_out,",\"dist\":%1.1f", (dist/totald)/1000.0);

	fprintf(g_out,"}");
}

void
thread_estimation_step (FILE *out, double timestamp, bool realtime)
{
	static uint32_t sequence = 0;

	if (realtime)
		usleep (200 * 1000);

	/* tracking dump state in JSON format */
	fprintf (out, "{\n  \"id\":%u,\n"
			"  \"api\":{\"name\":\"" PROGRAM_NAME "\",\"ver\":\""
			PROGRAM_VERSION "\"},\n" "  \"time\":%u,\n  \"edge\":[",
			sequence++, (uint32_t) timestamp);

	g_out = out;

	/* reset all tags */
	g_first = true;
	g_map_tag.IterateLocked (&thread_reset_tag, timestamp, realtime);

	/* display all edges */
	g_first = true;
	g_map_proximity.IterateLocked (&thread_iterate_prox, timestamp, realtime);

	/* display all tags */
	g_first = true;
	g_map_tag.IterateLocked (&thread_iterate_tag, timestamp, realtime);

	fprintf (out, "\n  ]\n},");

	/* propagate object on stdout */
	fflush (out);
}

int
main (int argc, char **argv)
{
	int mode;

	/* initialize statistics */
	g_unknown_reader = 0;
	g_decrypted_one = 0;
	g_total_crc_ok = g_total_crc_errors = 0;
	g_doubled_reader = 0;
	g_ignored_protocol = g_invalid_protocol = 0;

	g_map_tag.SetItemSize (sizeof (TTagItem));
	g_map_proximity.SetItemSize (sizeof (TTagProximity));

	/* initialize encryption */
	aes_init();

	/* check command line arguments */
	if (argc <= 1)
		return listen_packets (stdout);
	else
	{
		mode = (argc >= 3) ? atoi (argv[2]) : 0;

		/* mode one means realtime replay, zero or two maximum speed */
		parse_pcap (argv[1], mode == 1);

		/* if mode is two, then start listening */
		if(mode == 2)
			listen_packets (stdout);
	}
}

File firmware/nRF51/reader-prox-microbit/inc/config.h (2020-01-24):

/***************************************************************
 *
 * OpenBeacon.org - nRF51 board config files
 *
 * Copyright 2013-2015 Milosch Meriac <meriac@openbeacon.org>
 *
 ***************************************************************

 This file is part of the OpenBeacon.org active RFID firmware

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
*/
#ifndef __CONFIG_H__
#define __CONFIG_H__

#define CONFIG_UART_BAUDRATE UART_BAUDRATE_BAUDRATE_Baud115200
#define CONFIG_UART_BUFFER 2048
#define CONFIG_UART_FORCE_POWERED 1
#define CONFIG_UART_TXD_PIN  24
#define CONFIG_UART_RXD_PIN  25

#define CONFIG_BTN_A         17
#define CONFIG_BTN_B         26

#define LED_COLS              9
#define LED_ROWS              3
#define LED_COUNT             (LED_COLS+LED_ROWS)
#define LED_PIN_OFFSET        4
#define LED_MASK              (((1UL<<LED_COUNT)-1)<<LED_PIN_OFFSET)
#define LED_MASK_COLS         (((1UL<<LED_COLS)-1)<< LED_PIN_OFFSET)
#define LED_MASK_ROWS         (((1UL<<LED_ROWS)-1)<<(LED_PIN_OFFSET+LED_COLS))


/* only two priority bits available ! */

#define IRQ_PRIORITY_HIGH        0
#define IRQ_PRIORITY_AES         (IRQ_PRIORITY_HIGH)
#define IRQ_PRIORITY_RADIO       (IRQ_PRIORITY_HIGH+1)
#define IRQ_PRIORITY_POWER_CLOCK (IRQ_PRIORITY_HIGH+2)

#define IRQ_PRIORITY_LOW         (IRQ_PRIORITY_HIGH+3)
#define IRQ_PRIORITY_RTC0        (IRQ_PRIORITY_LOW)
#define IRQ_PRIORITY_RTC1        (IRQ_PRIORITY_LOW)
#define IRQ_PRIORITY_UART0       (IRQ_PRIORITY_LOW)

#endif/*__CONFIG_H__*/

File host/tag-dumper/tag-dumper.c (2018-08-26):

/***************************************************************
 *
 * OpenBeacon.org - Decode Tags Serial Port Dumps
 *
 * Copyright 2016 Milosch Meriac <milosch@meriac.com>
 *
 ***************************************************************/

/*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
 You should have received a copy of the GNU General Public License along
 with this program; if not, write to the Free Software Foundation, Inc.,
 51 Franklin Street, Fifth Floor, Boston, MA 02110-1301 USA.

 */

#include <stdarg.h>
#include <time.h>
#include <stdbool.h>
#include <stdint.h>
#include <string.h>
#include <stdlib.h>
#include <termios.h>
#include <stdio.h>
#include <sys/types.h>
#include <unistd.h>
#include <fcntl.h>

#define TAG_UART_BAUD_RATE 921600
#define BUFFER_SIZE 1024
#define PACKED __attribute__((packed))

#include "inc/openbeacon-proto.h"
#include "heatshrink_decoder.h"
#include "crc32.h"
#include "helper.h"

bool g_decoding;
heatshrink_decoder g_hsd;
uint32_t g_tag_id, g_page_count, g_group;
size_t g_out_pos;
TBeaconProxSighting g_sighting;

static int port_open(const char *device)
{
	int handle;
	struct termios options;

	/* open serial port */
	if((handle = open( device, O_RDONLY | O_NOCTTY | O_NDELAY)) == -1)
	{
		fprintf(stderr, "error: failed to open serial port (%s)\n", device);
		exit(10);
	}

	/* apply serial port settings */
	tcgetattr(handle, &options);
	cfmakeraw(&options);
	cfsetspeed(&options, TAG_UART_BAUD_RATE);

	if(tcsetattr(handle, TCSANOW, &options))
	{
		fprintf(stderr, "error: failed to set baud %i rate for '%s'\n", TAG_UART_BAUD_RATE, device);
		exit(11);
	}

	tcflush(handle, TCIFLUSH);

	return handle;
}

static void port_process_tag(void)
{
	fprintf(stdout,
		"{ \"tag_me\": \"0x%08X\", \"tag_them\": \"0x%08X\", \"time_local_s\": %8u, \"time_remote_s\": %8u, \"rssi\": %3i, \"angle\": %3i, \"group\": %u }\r\n",
		g_tag_id,
		g_sighting.tag_id,
		g_sighting.epoch_local,
		g_sighting.epoch_remote,
		g_sighting.power,
		g_sighting.angle,
		g_group);
}

static bool port_rx(uint8_t last_type, const uint8_t* buffer, int size)
{
	uint32_t crc, length;
	HSD_sink_res sres;
	HSD_poll_res pres;
	size_t in_pos, read, written;
	TBeaconProxSightingPage *page;

	switch(last_type)
	{
		case 0x01:
			if(size==sizeof(uint32_t))
			{
				g_tag_id = *((uint32_t*)buffer);
				fprintf(stderr, "Received Tag ID=0x%08X\n", g_tag_id);
			}
			break;

		case 0x02:
			if(size!=sizeof(*page))
				fprintf(stderr, "Received invalid page size of %i bytes\n", size);
			else
			{
				page = (TBeaconProxSightingPage*)buffer;

				/* abort decoding on log interruptions */
				if(page->length == 0xFFFF)
				{
					heatshrink_decoder_reset(&g_hsd);
					g_out_pos = 0;
					g_page_count++;
					g_decoding = false;
					break;
				}

				crc = crc32(page, sizeof(*page)-sizeof(page->crc32));
				length = page->length & BEACON_PROXSIGHTING_LENGTH_MASK;
				if((crc!=page->crc32) || (length>sizeof(page->buffer)))
				{
					fprintf(stderr, "Invalid page at page number %05i of size %i bytes (len=%i)\n",
						g_page_count, size, page->length);
					g_decoding = false;
				}
				else
				{
					/* restart decoding if new log is found */
					if(page->length & BEACON_PROXSIGHTING_PAGE_MARKER)
					{
						fprintf(stderr, "Found new log group[%u] at page %u\n",
							g_group, g_page_count);
						heatshrink_decoder_reset(&g_hsd);
						g_out_pos = 0;
						g_decoding = true;
						g_group++;
					}

					in_pos = 0;
					do {
						if((sres = heatshrink_decoder_sink(
							&g_hsd, &page->buffer[in_pos], sizeof(page->buffer)-in_pos, &read))<0)
						{
							fprintf(stderr, "ERROR: Invalid decoder result (%i)\n", sres);
							g_decoding = false;
							return false;
						}
						in_pos += read;

						do {
							written = 0;
							pres = heatshrink_decoder_poll(
								&g_hsd,
								((uint8_t*)&g_sighting) + g_out_pos,
								sizeof(g_sighting)-g_out_pos,
								&written);

							if(pres>=0)
							{
								g_out_pos+=written;

								if(g_out_pos==sizeof(g_sighting))
								{
									port_process_tag();
									g_out_pos = 0;
								}
							}
							else
							{
								fprintf(stderr, "ERROR: poll error %i\n", pres);
								g_decoding = false;
								return false;
							}
						} while(pres == HSDR_POLL_MORE);
					} while(in_pos<sizeof(page->buffer));
				}

				/* always increment page count independent of CRC */
				g_page_count++;
			}
			break;

		case 0x03:
			fprintf(stdout, "Terminated reception ot tag data.\n");
			g_tag_id = 0;
			g_decoding = false;
			break;
	}

	return true;
}

int main( int argc, const char* argv[] )
{
	int fd, i, pos;
	fd_set fds;
	int maxfd, res;
	bool escaped, done, overflow;
	uint8_t buffer_in[BUFFER_SIZE], buffer_out[BUFFER_SIZE], data, last_type;
	struct timeval timeout;

	if( argc < 2 )
	{
		fprintf (stderr, "usage: %s /dev/ttyUSB0\n", argv[0]);
		return 1;
	}

	/* initialize descriptor list */
	FD_ZERO(&fds);
	fd = port_open(argv[1]);
	maxfd = fd+1;


	/* initialize decompression library */
	heatshrink_decoder_reset(&g_hsd);

	/* loop over UART data */
	pos = 0;
	last_type = 0;
	escaped = done = overflow = false;
	while (!done)
	{
		/* set timeout value within input loop */
		timeout.tv_usec = 0; /* milliseconds */
		timeout.tv_sec  = 1; /* seconds */
		/* register descriptors */
		FD_SET(fd, &fds);
		/* wait for data, retry on timeout */
		if(select(maxfd, &fds, NULL, NULL, &timeout) == 0)
		{
			fprintf(stderr, ".");
			continue;
		}
		if(FD_ISSET(fd, &fds))
		{
			do {
				/* quit if end of file is reached */
				if((res = read(fd, buffer_in, BUFFER_SIZE))<=0)
					goto done;

				/* iterate through receive buffer */
				for(i=0; i<res; i++)
				{
					data = buffer_in[i];

					if(escaped)
					{
						escaped = false;

						switch(data)
						{
							/* deal with escaped 0xFF */
							case 0x00:
								if(pos<BUFFER_SIZE)
									buffer_out[pos++] = 0xFF;
								else
									overflow = true;
								break;

							/* transmission start */
							case 0x01:
								g_page_count = 0;
								last_type = data;
								pos = 0;
								break;

							/* frame start/end */
							case 0x02:
							case 0x03:
								if(overflow)
								{
									overflow = false;
									fprintf (stderr, "ERROR: overflow error, ignoring packet\n");
								}
								else
									if(pos && last_type)
									{
										if(!port_rx(last_type, buffer_out, pos))
											break;
									}
								last_type = data;
								pos = 0;
								fflush(stdout);
								break;

							default:
								fprintf (stderr, "ERROR: invalid character sequence (0x%02X)!\n", data);
								last_type = 0;
						}
					}
					else
					{
						if(data==0xFF)
							escaped = true;
						else
							if(pos<BUFFER_SIZE)
								buffer_out[pos++] = data;
							else
								overflow = true;
					}
				}
			} while (res == BUFFER_SIZE);
		}
	}

done:
	close(fd);
	return 0;
}

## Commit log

2014-03-25 enable accelerometer
2014-03-25 initialize input switch
2014-03-27 removed timer test
2014-03-27 added UART interrup support
2014-03-27 added UART comment
2014-03-28 added timer scheduling
2014-03-28 switched to IRQ listening
2014-03-29 fixed RSSI silicon bug
    [radio.c]
2014-03-29 added ADC battery measurement
2014-03-29 conditionally enable DC/DC based on battery voltage
2014-03-29 fixed ADC powerdown bug
    [adc.c]
2014-03-29 proximity listening based on timer IRQ
2014-03-29 changed WFI to WFE - ensure it's working in an interrupt as well.
2014-03-30 fixed 32kHz timer initialization
2014-03-30 fixed proximity RX/TX timing
    [config.h, radio.c]
2014-04-03 print device ID's on boot
2014-04-03 non-global device-id in main file
2014-04-03 switch to custom proximity protocol/address
2014-04-05 added accelerometer reading into main loop
2014-04-05 aligned printing of acceleration value
2014-04-06 simplified accelerometer initialization
2014-04-08 filter for log packets
2014-04-08 added AES function to rx code - broken
    [main.cpp]
2014-04-08 fixed AES function to rx code
    [main.cpp]
2014-04-09 show proximity slots
2014-04-14 added 'make demo' target and filter-singularsighting
2014-04-22 set proximity TX power to -20dBm
2014-05-11 fixed typo in comment
    [config.h]
2014-09-07 fixed radio IRQ config / decrease blink time
    [main.c, radio.c]
2014-09-07 transmit to old wireless mac address
2014-09-07 added flush, removed print_packet
2014-09-07 renamed tag-marker to tag-power
2014-10-04 allow raw accelerometer readings
2014-10-06 switched to readme in markdown format
2014-10-07 Published proximity tag hardware design
    [OpenBeacon-Tag-BL.PrjPCB, OpenBeacon.PcbDoc, OpenBeacon.SchDoc]
2014-10-23 changed interrupt priorities
2014-10-24 added broken RSSI measurement
    [main.c, radio.c]
2015-02-20 read both UARTs, remove framing
2015-02-20 added duplicate filtering
2015-03-07 allow UART to stay powered
2015-03-07 ensure that first packet is written into first slot
2015-03-17 timer controlled blinking
2015-03-18 added buggy name randomization code
    [config.h, main.c, radio.c]
2015-07-16 copied tag-power to tag-accel
2015-07-16 read at 1Mbit, print magnitude
2015-07-16 blink during print
2015-08-09 time-dependent weighted power measurement
2015-08-09 added fixed beacon positions
    [main.cpp]
2015-08-10 conditional reset of g_first
    [main.cpp]
2015-10-31 fixed full volume output
    [main.c]
2016-01-19 fixed gcc 5.2 compiler warning
    [main.c]
2016-02-13 added long/short range marker tag distinction
    [radio.c]
2016-02-14 fixed JSON formatting g_first bug / turned off replay-attack protection
    [main.cpp]
2016-02-14 fixed marker tag bit
    [main.c]
2016-02-21 update tag-power to latest packet format
2016-08-30 fixed accelerometer sign bug
    [acc.c]
2016-08-30 enabled power control for UART
2016-08-30 added adc_bat_sync() to enable sychronous ADC reading
2016-09-01 added heatshrink compression library
2016-10-17 added button-press support
2016-10-28 fix OSX compiler warning
    [tag-dumper.c]
2016-10-29 fix JSON format in packet tracer
    [main.cpp]
2016-11-15 increase power output to -16dBm for marker tag
2020-01-17 Fix gcc compiler warning
    [nrf5.c]
2020-01-20 Increase Volume & Add Workaround for PAN 73
    [main.c]
2020-01-24 Scale Voltage in 10th of Volts
2020-01-25 Fix line breaks in micro:bit serial log output
    [main.c]

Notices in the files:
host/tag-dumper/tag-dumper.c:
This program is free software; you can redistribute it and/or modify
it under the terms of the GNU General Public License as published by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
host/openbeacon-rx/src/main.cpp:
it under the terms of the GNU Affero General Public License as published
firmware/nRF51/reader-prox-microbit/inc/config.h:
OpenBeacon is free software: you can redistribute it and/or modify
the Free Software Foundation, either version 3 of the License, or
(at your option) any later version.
